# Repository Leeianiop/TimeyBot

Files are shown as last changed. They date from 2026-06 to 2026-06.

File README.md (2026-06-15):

# TimeyBot
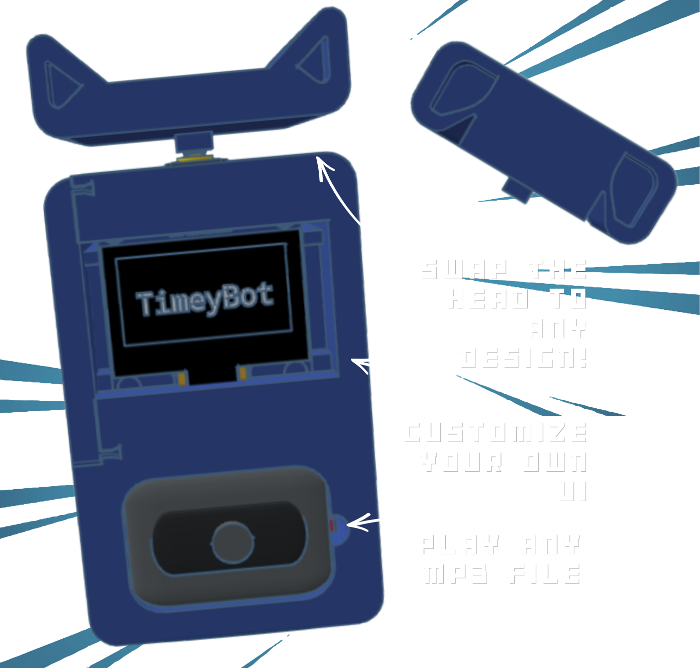
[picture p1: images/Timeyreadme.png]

## A cute Time tracker, Base functions include:
Stopwatch,
Timer,
Local Time,
Calendar reminder,
Alarm,
Music Player,
Pomodoro Tracker.
## Why Timey

It began when I was studying for exams; I always needed a study tool that was a time tracker and doubled as an audio player.  
Sure, there were phone apps to do so, but i kept finding myself scrolling whenever I go check on it.  
You could say I had been planing to make Timey for a long time  
It features all-in-one functions and can be built on to add your own Songs, Functions, Design and more.  
I made it specifically so that it doubles as a study partner, with time tracking and task reminder features and no distractions from other apps.    
## BOM

| Component | Description | Unit Price | Qty | Total |
|---|---|---|-----|---|
| ESP32 Dev Board (Micro USB) | Microcontroller | $6.03 | 1 | $6.03 |
| 128x64 1.3" OLED Display (I2C) | UI Display | $5.49 | 1 | $5.49 |
| 4Ω Speaker | Playing Music and Alarms | $3.63 | 1 | $3.63 |
| MAX98357 Amplifier | Amplify Sound | $3.27 | 1 | $3.27 |
| Jumper Wires (Female-Female) | Connect the Circuit | $1.48 | 1 | $1.48 |
| USB to Wires Cable | Power the Circuit | $1.75 | 1 | $1.75 |
| Push Button | Control the UI | $0.66 | 1 | $0.66 |
| Screw (10 pcs) | Locking in the PCB and components | $1.20 | 1 | $1.20 |
| Pin Header Female | Solder into PCB | $0.50 | 1 | $0.50 |
| DS3231 RTC module | Track local time offline | $2.21 | 1 | $2.21 |
| Pin Header Male (1x40) |Connecting components with PCB | $0.12 | 1 | $0.12 |
| 0805 SMD Ceramic Capacitor | Prevent brownout/ ESP crashes | $1.22 | 1 | $1.22 |
| Terminal Block 2p | To connect USB cable to esp | $0.12 | 1 | $0.12 |
| Hex Nut (M3) | To lock in button PCB and slider | $0.12 | 1 | $0.32 |

### Optional Storage Upgrade (For MP3 files)

| Component | Description | Price |
|---|---|---|
| Micro SD Card | Store MP3 Files | $1.13 |
| Micro SD Card Reader | Connect to ESP32 | $0.50 |

### Estimated Total Cost

**$29.33 USD**   

STL files include: (TimeyBotMainCase), (TimeyBotSlider), (TimeyBotBackplate), (Extensions file>> (TimeyBot_eDog), (TimeyBot_eCat) )  
PCB files include: (TimeyBotPCB), (TimeyBotSCH)   
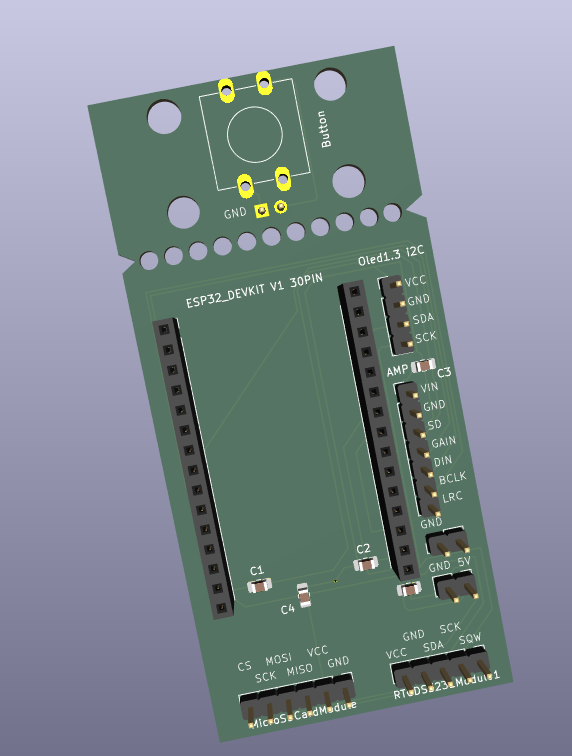
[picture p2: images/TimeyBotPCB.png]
TimeyBot
  
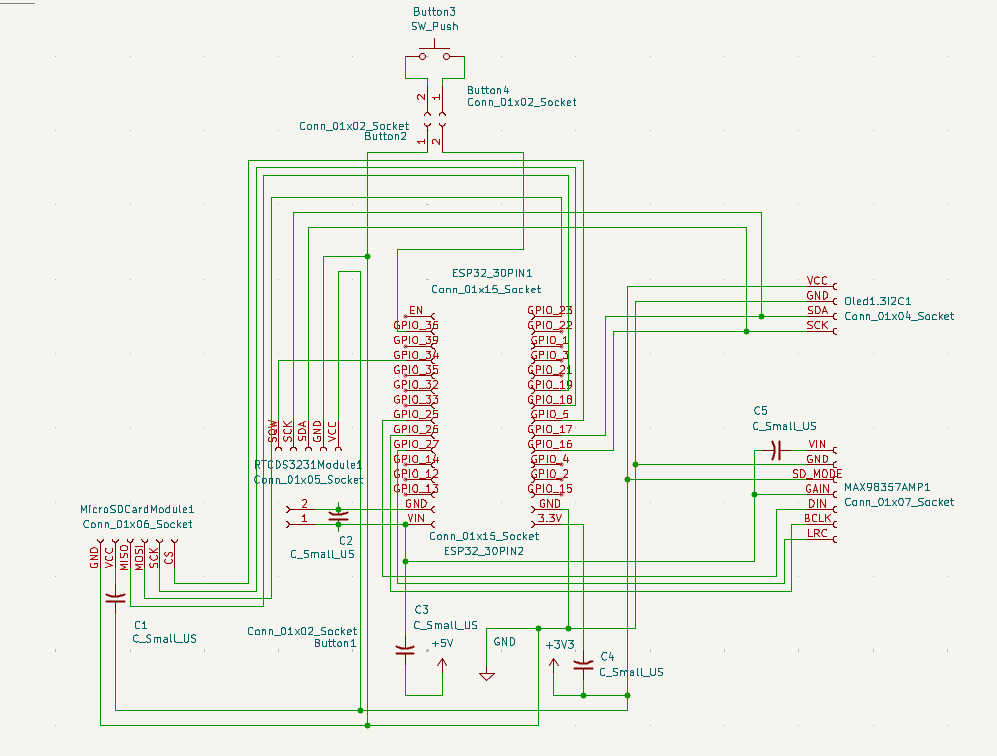
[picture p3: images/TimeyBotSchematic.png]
TimeyBot
  

## How to Use?
The starting page will be the Local Time Mode. Click the button on top (HEAD) to scroll down the menu and select different modes:
- Music Player Mode - Listening  
- Time Track Mode - Timer, Stopwatch, Alarm, Calendar Reminder  
- Study Mode - Pomodoro & Music  
## Setting up
1. Print the STL files.  
2. Upload the IDE code into the ESP32, remember to install ESP Boards and Adafruit Libraries. 
3. Wire the components into the case as shown in the Wiring Diagram or Get the PCB board and connect according so.
4. PCB goes and RTC and SD and AMP go behind where they are labeled in the STL file :)  
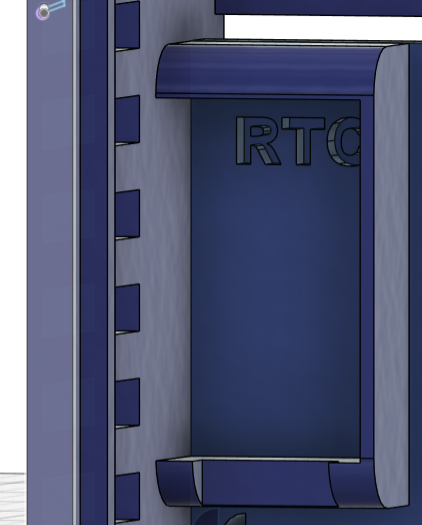
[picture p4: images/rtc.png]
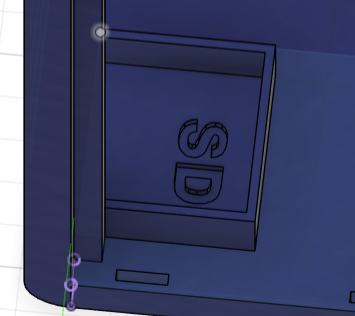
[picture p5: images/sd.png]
  
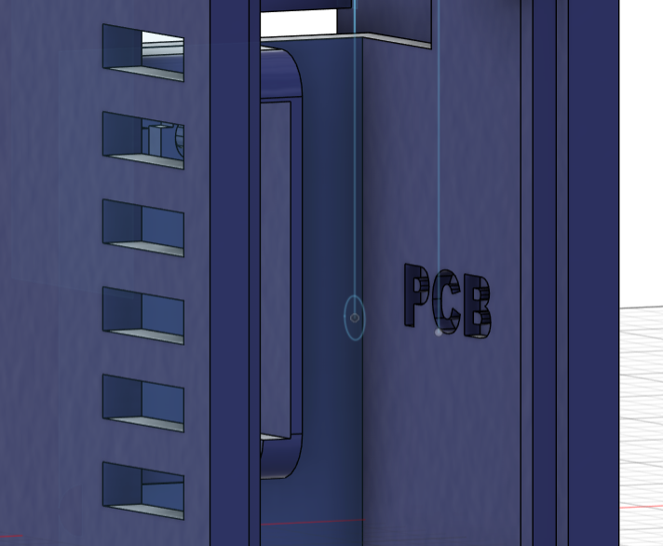
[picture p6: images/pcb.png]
   
Hope you like Mr Timey ;) 35 hours logged on this project (as of now)

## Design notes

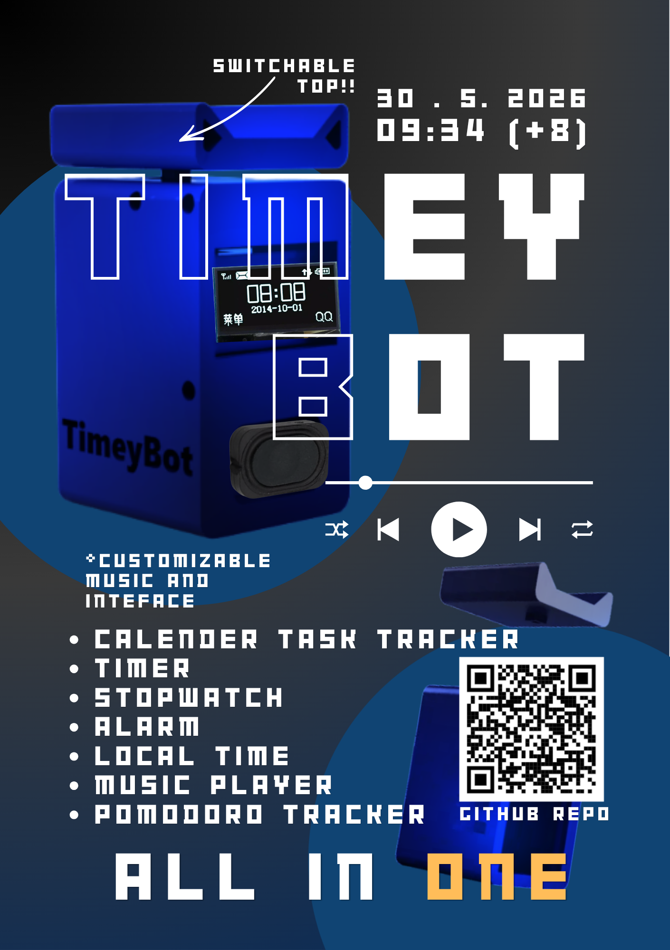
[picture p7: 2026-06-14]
images/TimeyBotZine.png

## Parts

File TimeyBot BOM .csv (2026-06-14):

Components | Description | Link | Unit Price ($) | Quantity | Total ($)
ESP32 Dev Board (microusb) | Microcontroller | https://www.lazada.com.my//products/i4353659237-s24471519541.html?urlFlag=true | $6.03 | 1 | $6.03
128x64 1.3inch Oled display (I2C) | UI display | https://www.lazada.com.my//products/i4565300946-s25774984786.html?urlFlag=true | $5.49 | 1 | $5.49
4 ohm speaker | Playing Music and Alarms | https://www.lazada.com.my//products/i4151232045-s23547423704.html?urlFlag=true | $3.63 | 1 | $3.63
MAX98357 amp | Amplify sound | https://www.lazada.com.my//products/i4826031585-s27348421411.html?urlFlag=true | $3.27 | 1 | $3.27
Jumper wires (female to female) | Connect the circuit | https://www.lazada.com.my//products/i3898574832-s22557322350.html?urlFlag=true | $1.48 | 1 | $1.48
USB to wire cable | Wire to power the circuit | https://www.lazada.com.my//products/i4633393867-s26061046516.html?urlFlag=true | $1.75 | 1 | $1.75
Push Button | Control the UI | https://www.lazada.com.my//products/i4842604827-s27498071360.html?urlFlag=true | $0.66 | 1 | $0.66
Screw (10 pcs) | Locking in the PCB and components | https://www.lazada.com.my//products/i4663837363-s26181719273.html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 | $1.20 | 1 | $1.20
Pin Header Female (1x40) | Connecting ESP with PCB | https://www.lazada.com.my//products/i4663837363-s26181719273.html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 | $0.20 | 1 | $0.20
DS3231 RTC module | Track local time offline | https://www.lazada.com.my//products/i131084606-s146041975.html?urlFlag=true&tradePath=%2CcartPriceDrop%2Ccart | $2.21 | 1 | $2.21
Pin Header Male (1x40) | Connecting components with PCB | https://www.lazada.com.my//products/i421963311-s614288662.html?urlFlag=true | $0.12 | 1 | $0.12
0805 SMD Ceramic Capacitor | Prevent brownout/ ESP crashes | https://shopee.com.my/product/265108724/42621557099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 | $1.22 | 1 | $1.22
Terminal Block 2p | To connect USB cable to esp | https://www.lazada.com.my//products/i4060872536-s22979351303.html?urlFlag=true | $0.12 | 1 | $0.12
Hex Nut (M3) | To lock in button PCB and slider | https://www.lazada.com.my//products/i2448181222-s10645857289.html?urlFlag=true | $0.32 | 1 | $0.32
Optional (Larger songs storage)
Micro SD card | Store MP3 files | https://www.lazada.com.my//products/i3905404564-s22583718858.html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 | $0.50 | 1 | $0.50
Micro SD card reader | Connect to ESP32 | https://www.lazada.com.my//products/i14860303701-s127831463438.html?urlFlag=true | $1.13 | 1 | $1.13
 |  |  |  | TOTAL: | $29.33

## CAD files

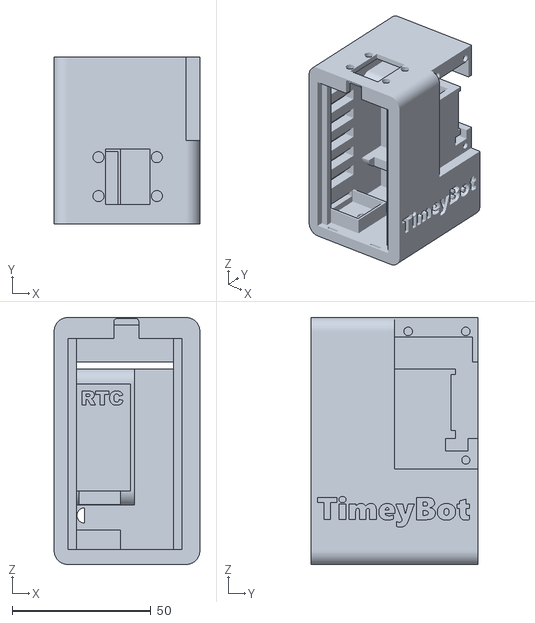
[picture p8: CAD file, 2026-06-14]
CAD/STL/TimeyBotMainCase.stl
52.5 x 60.0 x 88.9

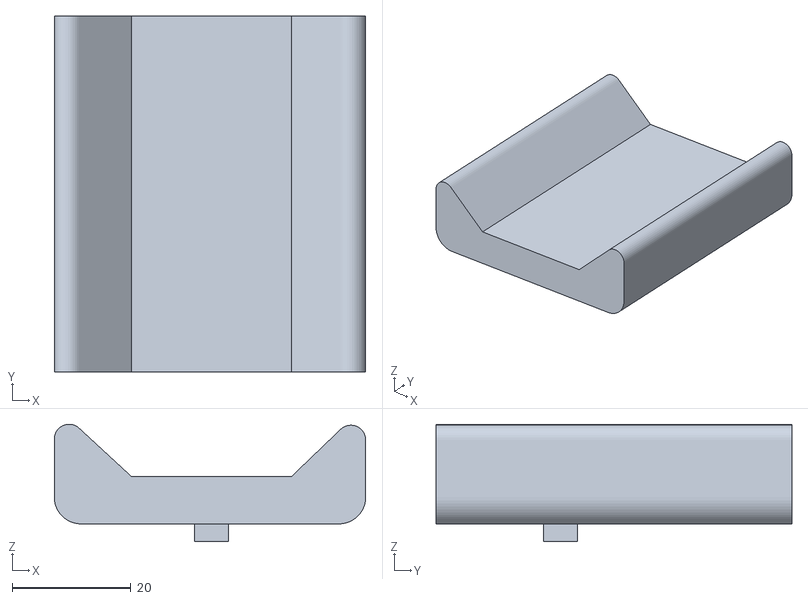
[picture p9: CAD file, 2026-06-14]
CAD/STL/Extentions/TimeyBot_eCat.stl
52.5 x 60.0 x 19.8

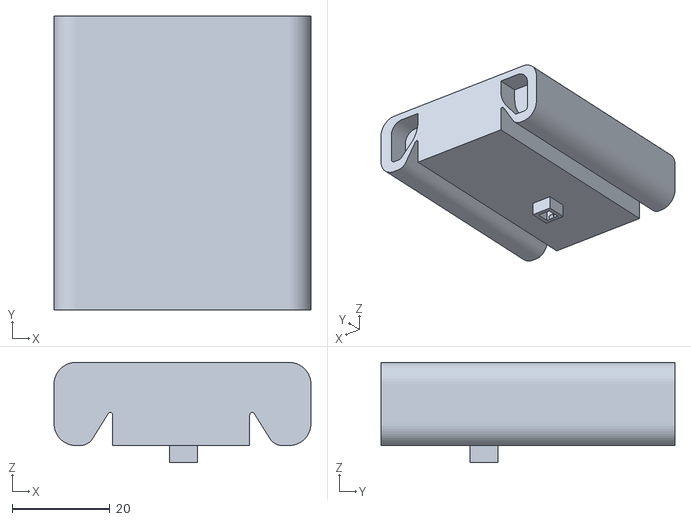
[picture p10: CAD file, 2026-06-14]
CAD/STL/Extentions/TimeyBot_eDog.stl
52.5 x 60.0 x 20.5

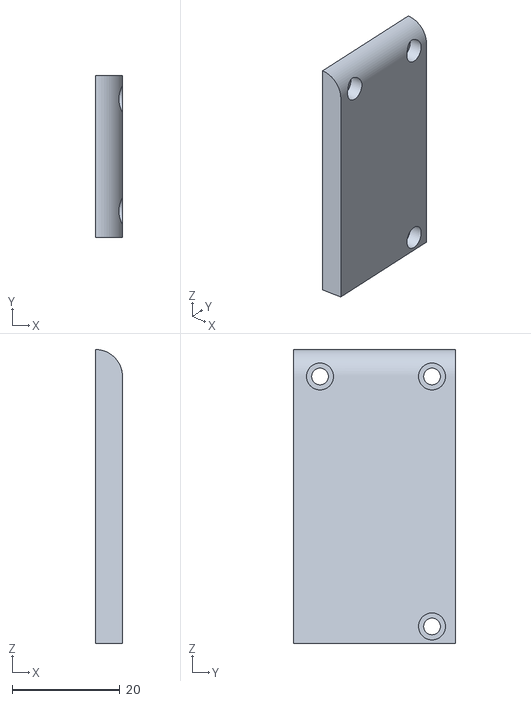
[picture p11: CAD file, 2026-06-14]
CAD/STL/TimeyBotSlider.stl
5.00 x 30.0 x 54.5

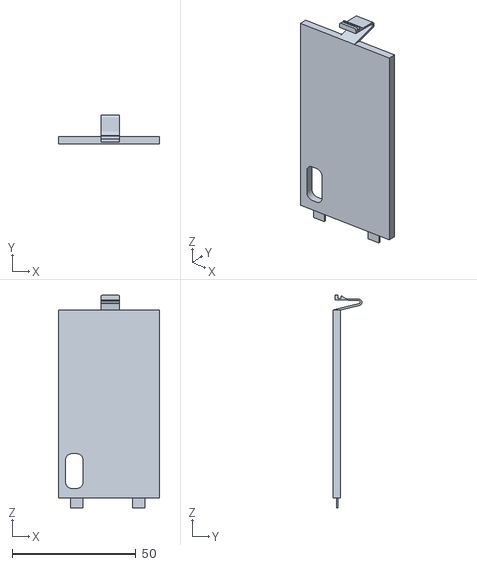
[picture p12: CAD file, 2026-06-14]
CAD/STL/TimeyBotBackplate.stl
40.8 x 11.7 x 85.9

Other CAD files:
CAD/F3D/Extentions/TimeyBot.eCat.f3d
CAD/F3D/Extentions/TimeyBot_eDog.f3d
CAD/F3D/TimeyBotBackplate.f3d
CAD/F3D/TimeyBotMainCase.f3d
CAD/F3D/TimeyBotSlider.f3d

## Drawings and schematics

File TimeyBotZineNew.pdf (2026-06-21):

# T i m e y

# T i m e y

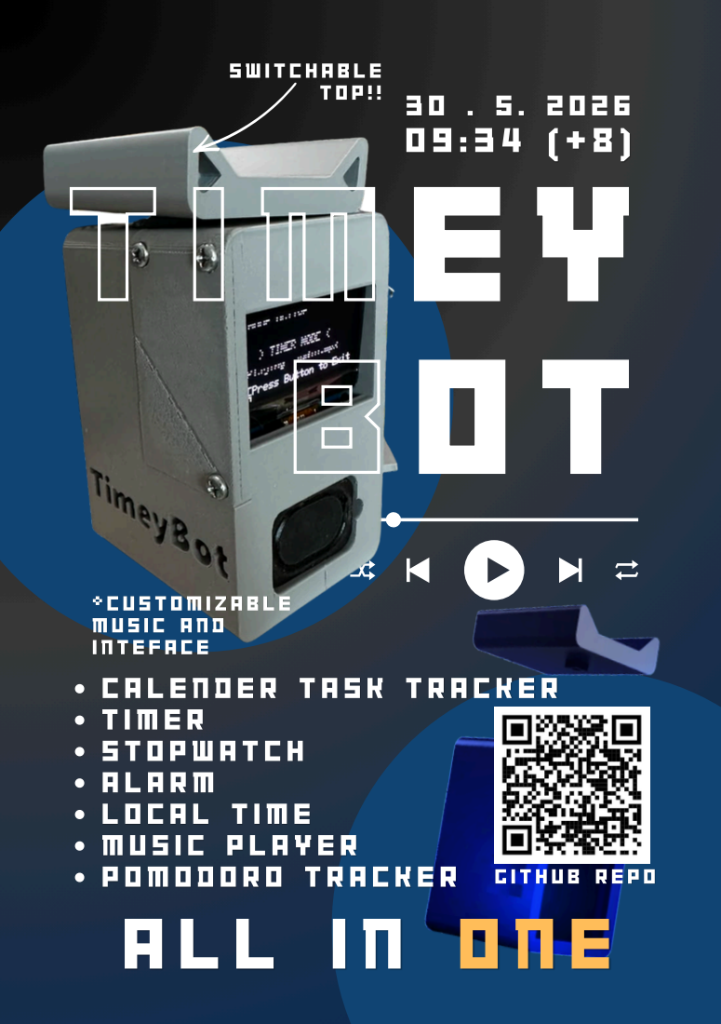
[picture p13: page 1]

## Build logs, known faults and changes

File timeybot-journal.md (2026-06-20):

# TimeyBot — Journal Export

- Exported at: 2026-06-20T15:19:27Z
- Project ID: 3963
- Entries: 25

## Entry 1
- ID: 9626
- Author: leeianiop
- Created At: 2026-05-27T10:57:30Z

### Content

TimeyBot casing done, those moments where i pause is when i'm getting the real measurements IRL haha.
I had a oled display and a speaker ready to build in.
Now that i'm thinking about it i should probably add some buttons too.
Anyways i'm using a esp32s node mcu as the microcontroller.
For the casing i added slot in features so i can reuse the components
Screenshot 2026-05-27 185709.png

### Recording Links

- https://lookout.hackclub.com/api/media/aca936d9-4302-4b63-9ccd-78aa38902488/video.mp4
- https://lookout.hackclub.com/api/media/b4b0e7d0-71a9-43bd-9ff9-4062f8d3f2a6/video.mp4
- https://lookout.hackclub.com/api/media/941186ab-774c-48eb-93c7-11b908e6de81/video.mp4

## Entry 2
- ID: 9785
- Author: leeianiop
- Created At: 2026-05-28T01:13:31Z

### Content

Made the back case pullable out with a mechanism i found from my aircon remote haha.
I also added a hole for a button at the top. 
Screenshot 2026-05-28 091316.png

### Recording Links

- https://lookout.hackclub.com/api/media/1df0b7c0-1a78-4813-b53f-61819b8887a2/video.mp4

## Entry 3
- ID: 9795
- Author: leeianiop
- Created At: 2026-05-28T02:27:48Z

### Content

Troubleshooting with printer settings and support however cannot seem to connect to the bambulab printer
Screenshot 2026-05-28 102736.png

### Recording Links

- https://lookout.hackclub.com/api/media/a85a095e-26fb-4f63-81f8-66f27bd3c90f/video.mp4
- https://lookout.hackclub.com/api/media/1affa838-77b3-40f8-9c1d-164167250a16/video.mp4
- https://lookout.hackclub.com/api/media/6a5180d8-5217-4733-aecd-22dafd21f26a/video.mp4

## Entry 4
- ID: 9825
- Author: leeianiop
- Created At: 2026-05-28T03:46:10Z

### Content

more troubleshooting with the bambu studio. tested different supports and infills along with slicing and printing the model
Screenshot 2026-05-28 114503.png

### Recording Links

- https://lookout.hackclub.com/api/media/5c71a48b-4f21-463b-a1da-840a61b8d239/video.mp4
- https://lookout.hackclub.com/api/media/1c1d758c-5e23-4d0c-b9d4-b4ee772af2d7/video.mp4

## Entry 5
- ID: 9842
- Author: leeianiop
- Created At: 2026-05-28T05:46:45Z

### Content

Finally got it printing. Managed to connect to the public printer. Had to adjust the nozzle head print size to 0.4mm, which was the error I was struggling with.
Screenshot 2026-05-28 134628.png

### Recording Links

- https://lookout.hackclub.com/api/media/663155b8-820d-4612-9923-2deb1a33bc95/video.mp4

## Entry 6
- ID: 9951
- Author: leeianiop
- Created At: 2026-05-28T17:19:43Z

### Content

Made some cute head designs to put on the button, it will look like you are petting the timer when you are using the UI. Had some concerns about the stability of it though, will need to ptrint and test one of the caps in the future
Screenshot 2026-05-29 004737.png

### Recording Links

- https://lookout.hackclub.com/api/media/dfa268cd-a97c-4cdf-9e24-2dcb3797ff1c/video.mp4
- https://lookout.hackclub.com/api/media/069e8b3b-81d4-4465-9951-9a41faa7e57b/video.mp4
- https://lookout.hackclub.com/api/media/595c66b7-45be-4036-a471-099ad555ba8f/video.mp4

## Entry 7
- ID: 10127
- Author: leeianiop
- Created At: 2026-05-29T12:36:18Z

### Content

Preparing the GitHub page of TimeyBot and started making my BOM. Had to use lazada as it has the cheapest prices in my local area and can ship quickly
Screenshot 2026-05-29 203602.png

### Recording Links

- https://lookout.hackclub.com/api/media/58fa0497-983c-4c81-a635-950b61feb98a/video.mp4

## Entry 8
- ID: 10413
- Author: leeianiop
- Created At: 2026-05-30T14:31:52Z

### Content

Started rendering designs at Fusion360 to put into My Zine and Github. Project is eensy weensy bit from submitting!
TimeyBot v256.png

### Recording Links

- https://lookout.hackclub.com/api/media/4234852c-8d47-484a-8153-8b92821760e3/video.mp4

## Entry 9
- ID: 10426
- Author: leeianiop
- Created At: 2026-05-30T15:50:46Z

### Content

Rendered some more images and started working on my zine. Thought it turned out pretty nice. Would work more on the zine if i get to build it IRL though.
Screenshot 2026-05-30 235028.png

### Recording Links

- https://lookout.hackclub.com/api/media/0a092aab-06f9-42a0-9b52-7a3acb63f3b1/video.mp4
- https://lookout.hackclub.com/api/media/e49a1ca9-9b91-457e-abcf-951449487bef/video.mp4

## Entry 10
- ID: 10658
- Author: leeianiop
- Created At: 2026-05-31T14:02:12Z

### Content

Updated the README to fit the requirements, included how to use and how to set up the bot. Also the Functionality of it too
Screenshot 2026-05-31 220148.png

### Recording Links

- https://lookout.hackclub.com/api/media/4a583a6b-3a67-41ce-bc6b-1b74bc771ffe/video.mp4

## Entry 11
- ID: 10862
- Author: leeianiop
- Created At: 2026-06-01T09:02:05Z

### Content

Realized some parts needed strong fixing. Added screw holes to the slider. Changed the back plate to a better design (which I looked at my remote for inspo :|) Made the button on top screwable too which means i'm going to make a pcb! Also added a hole in the back plate for the cable to pass through and a place to hold the sd card reader.
Screenshot 2026-06-01 165823.png
Screenshot 2026-06-01 165858.png
Screenshot 2026-06-01 165843.png
Screenshot 2026-06-01 170055.png

### Recording Links

- https://lookout.hackclub.com/api/media/66f31b4e-5d65-4539-a3e5-536cd677eb44/video.mp4

## Entry 12
- ID: 11119
- Author: leeianiop
- Created At: 2026-06-02T12:50:17Z

### Content

Added some more improvements in fusion360 ( added components, fixed spacing in the back for PCB and screws etc)
Screenshot 2026-06-02 205004.png

### Recording Links

- https://lookout.hackclub.com/api/media/eaad9281-3e57-4cba-927e-977e82870d98/video.mp4

## Entry 13
- ID: 11394
- Author: leeianiop
- Created At: 2026-06-03T15:56:59Z

### Content

Not much of a code guy, just touched on Arduino code few weeks ago, this was so much PAIN.  I typed the base code for first functions and messed up some of the indentations. Lets see if i can finish this in a week AT LEAST.
Screenshot 2026-06-03 235647.png

### Recording Links

- https://lookout.hackclub.com/api/media/b4ea31a1-70b8-4024-958e-bc2022d59612/video.mp4
- https://lookout.hackclub.com/api/media/4d4cc00d-22d9-4270-8269-72749c7ad194/video.mp4
- https://lookout.hackclub.com/api/media/deecaf63-86ad-40e9-962d-6f7d2487d171/video.mp4

## Entry 14
- ID: 12761
- Author: leeianiop
- Created At: 2026-06-09T14:05:11Z

### Content

Finally started working on the PCB, i'm thinking of having 2 separate pieces. All components connect to pcb to link the gnd and power input, also rtc module and oled share the same i2c bus connection
Screenshot 2026-06-09 214531.png

### Recording Links

- https://lookout.hackclub.com/api/media/33836b4c-7d7f-40ad-9e0a-580c6e93ade7/video.mp4
- https://lookout.hackclub.com/api/media/ca30adea-8576-4a6e-8326-14cfa5c02f43/video.mp4
- https://lookout.hackclub.com/api/media/eb6b7f75-2b40-4dc2-bb2c-49a14868603e/video.mp4
- https://lookout.hackclub.com/api/media/78d7e940-a44e-48e8-a492-8e8bf6607fb3/video.mp4
- https://lookout.hackclub.com/api/media/73bc249c-82d6-4d26-90f1-290dd2503605/video.mp4
- https://lookout.hackclub.com/api/media/7655375c-11f6-41e5-b040-906e9dcfa117/video.mp4

## Entry 15
- ID: 13015
- Author: leeianiop
- Created At: 2026-06-10T14:37:16Z

### Content

Screenshot 2026-06-10 222900.png
Made the PCB and 3d model,  all components will be connected with jumper wires, except for the RTC module.

### Recording Links

- https://lookout.hackclub.com/api/media/8cdbccbf-77c3-4fcf-851f-fd816c45c0c8/video.mp4

## Entry 16
- ID: 13207
- Author: leeianiop
- Created At: 2026-06-11T11:05:52Z

### Content

Made a new pcb because the first one didn't fit, and added the button pin header, gonna add mounting holes next
Screenshot 2026-06-11 190542.png

### Recording Links

- https://lookout.hackclub.com/api/media/2806812f-cc04-4156-ae7f-921718eb8e70/video.mp4

## Entry 17
- ID: 13222
- Author: leeianiop
- Created At: 2026-06-11T13:07:20Z

### Content

Made screws/ mounting holes for the button PCB. was crashing out because the lines kept changing nets. (speaking of nets the world cup is about to start (random))
Screenshot 2026-06-11 210324.png

### Recording Links

- https://lookout.hackclub.com/api/media/cf07cd95-1e78-4824-a3a8-8bfcd8826d7b/video.mp4

## Entry 18
- ID: 13661
- Author: leeianiop
- Created At: 2026-06-13T06:54:33Z

### Content

I made some firmware. Tested to use which pins and library, and learned some oled programming basics. 
Screenshot 2026-06-13 145417.png

### Recording Links

- https://lookout.hackclub.com/api/media/7df9c961-e835-4e45-be9e-13f5cd94508c/video.mp4

## Entry 19
- ID: 13671
- Author: leeianiop
- Created At: 2026-06-13T07:43:16Z

### Content

Made some fusion progress, added an RTC housing cage, and also added text at the back for other users to know which parts go where.
Screenshot 2026-06-13 154304.png

### Recording Links

- https://lookout.hackclub.com/api/media/2905d5b5-91f6-45b1-8517-32c81bcb9b92/video.mp4

## Entry 20
- ID: 13760
- Author: leeianiop
- Created At: 2026-06-13T16:36:39Z

### Content

Made the PCB into one peice and made the top breakable for the button PCB. Also had to swtich the esp to the left side to prevent sizing problems with the RTC module. Rendered some CAD images and edited the zine and BOM as well.
Screenshot 2026-06-14 003629.png

### Recording Links

- https://lookout.hackclub.com/api/media/f2edabfc-0006-4ef3-a692-de537cd8164d/video.mp4

## Entry 21
- ID: 13923
- Author: leeianiop
- Created At: 2026-06-14T09:12:56Z

### Content

Screenshot 2026-06-14 171052.png
Measured the back compartments in fsion and realized there was no space, had to remake the PCB (3RD TIME!!) at least i have the final PCB now and everything fits

### Recording Links

- https://lookout.hackclub.com/api/media/93eea880-acfb-4b24-9d4c-3b102e27579c/video.mp4

## Entry 22
- ID: 13949
- Author: leeianiop
- Created At: 2026-06-14T11:04:03Z

### Content

I did some fusion exporting to bambu lab and updated the github with new PCB and CAD models along with the new zine 
Screenshot 2026-06-14 180019.png

### Recording Links

- https://lookout.hackclub.com/api/media/3b24968e-e1ac-4d63-a888-68967dfeedab/video.mp4

## Entry 23
- ID: 14205
- Author: leeianiop
- Created At: 2026-06-15T09:29:41Z

### Content

Average firmware crash out. I tried the full code, my oled doesn't even light up. I tried a test code and it crashed. The thrid time it uploaded but my oled still malfunctioning. Will check on the hardware problem, maybe its a cable issue
Screenshot 2026-06-15 172807.png

### Recording Links

- https://lookout.hackclub.com/api/media/4f8b9889-aa07-45fa-8969-e430c02bb2f0/video.mp4

## Entry 24
- ID: 14241
- Author: leeianiop
- Created At: 2026-06-15T13:28:00Z

### Content

My programming cable is likely the issue, the UI keeps resetting, i will have to trust my code untill i get a better one :(
Screenshot 2026-06-15 212705.png

### Recording Links

- https://lookout.hackclub.com/api/media/bb54c09f-d2da-4d2e-b311-0708fed76065/video.mp4

## Entry 25
- ID: 14250
- Author: leeianiop
- Created At: 2026-06-15T14:27:12Z

### Content

I did some final checking on the repo, added teh gerber fies, and ino files and some images in the readme as well
Screenshot 2026-06-15 222653.png

### Recording Links

- https://lookout.hackclub.com/api/media/cbd69450-d8c1-4c18-bc44-79310bb84149/video.mp4

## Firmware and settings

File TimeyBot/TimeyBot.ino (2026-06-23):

#define AUDIO_NO_WEB    
#define AUDIO_NO_WAV    
#define AUDIO_NO_FLAC
#define AUDIO_NO_AAC
#define AUDIO_NO_M4A

#include <Wire.h>
#include <SPI.h>
#include <Adafruit_GFX.h>
#include <Adafruit_SSD1306.h>
#include "Audio.h" 
#include "LittleFS.h"

// ---------------- OLED SPI Pins ----------------
#define SCREEN_WIDTH 128
#define SCREEN_HEIGHT 64
#define OLED_MOSI 23
#define OLED_CLK  18
#define OLED_DC   16
#define OLED_CS   5
#define OLED_RESET 17

Adafruit_SSD1306 display(SCREEN_WIDTH, SCREEN_HEIGHT, &SPI, OLED_DC, OLED_RESET, OLED_CS);

// ---------------- Audio & Button Pins ----------------
#define BUTTON_PIN 4
#define I2S_BCLK   26
#define I2S_LRC    25
#define I2S_DOUT   27

Audio audio;

// ---------------- UI States ----------------
enum UIState {
  STATE_SET_HOURS,      
  STATE_SET_MINUTES,    
  STATE_CONFIRM_SETUP,  
  STATE_CLOCK,
  STATE_MENU,
  STATE_TIMER,          // Fully coded
  STATE_ALARM_HOURS,    // Fully coded dynamic settings
  STATE_ALARM_MINUTES,  
  STATE_ALARM_ACTIVE,   
  STATE_STOPWATCH,      // Fully coded
  STATE_SOUND_PLAY
};

UIState currentState = STATE_SET_HOURS; 
int menuSelection = 0; 
int scrollOffset = 0; 
const int MENU_ITEMS_COUNT = 5;
const char* menuItems[] = {
  "Timer Mode", 
  "Alarm Set", 
  "Stopwatch", 
  "Songs (Earrings)", 
  "< Back to Clock"
};

int confirmSelection = 0; 

// ---------------- Button Timing Variables ----------------
unsigned long lastButtonPressTime = 0;
bool singleClickPending = false;
unsigned long doubleClickGap = 250; 

// ---------------- Clock Variables ----------------
unsigned long lastClockUpdate = 0;
int hours = 0;
int minutes = 0;
int seconds = 0; 

// ---------------- Mode Functional Variables ----------------
// Timer variables
int timerTargetMinutes = 1; 
unsigned long timerStartTime = 0;
unsigned long timerDurationMs = 0;
bool timerRunning = false;

// Alarm variables
int alarmHours = 0;
int alarmMinutes = 0;
bool alarmEnabled = false;
bool alarmRinging = false;

// Stopwatch variables
unsigned long stopwatchElapsedMs = 0;
unsigned long stopwatchLastPausedMs = 0;
unsigned long stopwatchStartTime = 0;
bool stopwatchRunning = false;

void setup() {
  pinMode(BUTTON_PIN, INPUT_PULLUP);
  Serial.begin(115200);

  if (!display.begin(SSD1306_SWITCHCAPVCC)) {
    Serial.println("OLED allocation failed");
    while (1);
  }

  display.clearDisplay();
  display.setTextColor(SSD1306_WHITE);
  display.setTextWrap(false);

  if(!LittleFS.begin()){
     Serial.println("An Error has occurred while mounting LittleFS");
  }

  audio.setPinout(I2S_BCLK, I2S_LRC, I2S_DOUT);
  audio.setVolume(12); 
}

void loop() {
  audio.loop();

  // --- Dynamic Double Click Adjustment ---
  if (currentState == STATE_SET_HOURS || currentState == STATE_SET_MINUTES || currentState == STATE_ALARM_HOURS || currentState == STATE_ALARM_MINUTES) {
    doubleClickGap = 180; 
  } else {
    doubleClickGap = 350; 
  }

  // --- Button Input Logic ---
  static bool lastButtonState = HIGH;
  bool currentButtonState = digitalRead(BUTTON_PIN);
  bool actionScroll = false;
  bool actionEnter = false;

  if (lastButtonState == HIGH && currentButtonState == LOW) {
    unsigned long clickTime = millis();
    if (clickTime - lastButtonPressTime < doubleClickGap) {
      actionEnter = true;          
      singleClickPending = false;  
    } else {
      singleClickPending = true;   
    }
    lastButtonPressTime = clickTime;
    delay(60); 
  }
  lastButtonState = currentButtonState;

  if (singleClickPending && (millis() - lastButtonPressTime > doubleClickGap)) {
    actionScroll = true;
    singleClickPending = false;
  }

  // --- Background Clock Tracker ---
  if (currentState != STATE_SET_HOURS && currentState != STATE_SET_MINUTES && currentState != STATE_CONFIRM_SETUP) {
    if (millis() - lastClockUpdate >= 1000) {
      lastClockUpdate = millis();
      seconds++;
      if (seconds >= 60) {
        seconds = 0;
        minutes++;
        if (minutes >= 60) {
          minutes = 0;
          hours++;
          if (hours >= 24) hours = 0;
        }
      }
      
      // Check active alarm match once per minute change
      if (alarmEnabled && seconds == 0 && hours == alarmHours && minutes == alarmMinutes) {
        alarmRinging = true;
        currentState = STATE_SOUND_PLAY;
        audio.connecttoFS(LittleFS, "/Earrings.mp3");
      }
    }
  }

  // --- UI Logic State Machine ---
  switch (currentState) {
    case STATE_SET_HOURS:
      if (actionScroll) { hours++; if (hours >= 24) hours = 0; }
      if (actionEnter) { currentState = STATE_SET_MINUTES; delay(150); }
      break;

    case STATE_SET_MINUTES:
      if (actionScroll) { minutes++; if (minutes >= 60) minutes = 0; }
      if (actionEnter) { currentState = STATE_CONFIRM_SETUP; confirmSelection = 0; delay(150); }
      break;

    case STATE_CONFIRM_SETUP:
      if (actionScroll) confirmSelection = (confirmSelection == 0) ? 1 : 0;
      if (actionEnter) {
        if (confirmSelection == 0) { lastClockUpdate = millis(); seconds = 0; currentState = STATE_CLOCK; }
        else { currentState = STATE_SET_HOURS; }
        delay(150);
      }
      break;

    case STATE_CLOCK:
      if (actionScroll || actionEnter) { currentState = STATE_MENU; menuSelection = 0; scrollOffset = 0; }
      break;

    case STATE_MENU:
      if (actionScroll) {
        menuSelection++;
        if (menuSelection >= MENU_ITEMS_COUNT) { menuSelection = 0; scrollOffset = 0; }
        if (menuSelection - scrollOffset >= 2) scrollOffset++;
      }
      if (actionEnter) {
        if (menuSelection == 0)      { currentState = STATE_TIMER; timerRunning = false; }
        else if (menuSelection == 1) { currentState = STATE_ALARM_HOURS; alarmHours = 0; }
        else if (menuSelection == 2) { currentState = STATE_STOPWATCH; }
        else if (menuSelection == 3) {
          currentState = STATE_SOUND_PLAY;
          alarmRinging = false;
          audio.connecttoFS(LittleFS, "/Earrings.mp3");
        } 
        else if (menuSelection == 4) currentState = STATE_CLOCK;
        delay(150);
      }
      break;

    case STATE_TIMER:
      if (!timerRunning) {
        if (actionScroll) { timerTargetMinutes++; if (timerTargetMinutes > 60) timerTargetMinutes = 1; }
        if (actionEnter) { timerRunning = true; timerStartTime = millis(); timerDurationMs = (unsigned long)timerTargetMinutes * 60000; }
      } else {
        if (actionEnter) { timerRunning = false; } // Interrupted/Cancel
        if (millis() - timerStartTime >= timerDurationMs) {
          timerRunning = false;
          currentState = STATE_SOUND_PLAY;
          audio.connecttoFS(LittleFS, "/Earrings.mp3");
        }
      }
      if (actionScroll && timerRunning) { currentState = STATE_MENU; timerRunning = false; } // Exit if scrolled while running
      break;

    case STATE_ALARM_HOURS:
      if (actionScroll) { alarmHours++; if (alarmHours >= 24) alarmHours = 0; }
      if (actionEnter) { currentState = STATE_ALARM_MINUTES; alarmMinutes = 0; delay(150); }
      break;

    case STATE_ALARM_MINUTES:
      if (actionScroll) { alarmMinutes++; if (alarmMinutes >= 60) alarmMinutes = 0; }
      if (actionEnter) { alarmEnabled = true; currentState = STATE_ALARM_ACTIVE; delay(150); }
      break;

    case STATE_ALARM_ACTIVE:
      if (actionScroll) { alarmEnabled = false; currentState = STATE_MENU; } // Disable alarm
      if (actionEnter) { currentState = STATE_MENU; } // Keep active, exit menu view
      break;

    case STATE_STOPWATCH:
      if (actionScroll) { // Pause / Unpause toggle
        if (!stopwatchRunning) {
          stopwatchRunning = true;
          stopwatchStartTime = millis() - stopwatchElapsedMs;
        } else {
          stopwatchRunning = false;
          stopwatchElapsedMs = millis() - stopwatchStartTime;
        }
      }
      if (actionEnter) { // Reset or Back control
        if (stopwatchElapsedMs == 0 && !stopwatchRunning) {
          currentState = STATE_MENU;
        } else {
          stopwatchRunning = false;
          stopwatchElapsedMs = 0;
        }
      }
      break;

    case STATE_SOUND_PLAY:
      if (actionEnter || actionScroll) { 
        audio.stopSong(); 
        currentState = alarmRinging ? STATE_ALARM_ACTIVE : STATE_MENU;
        alarmRinging = false;
      }
      break;
  }

  // --- Render to Display ---
  display.clearDisplay();
  display.setTextColor(SSD1306_WHITE); 

  if (currentState == STATE_SET_HOURS) {
    display.setTextSize(1); display.setCursor(16, 6); display.print("SETUP: SET HOUR");
    display.setTextSize(4); display.setCursor(40, 20);
    if(hours < 10) display.print("0"); display.print(hours);
    display.setTextSize(1); display.setCursor(6, 54); display.print("Clk: +1 | Dbl: Next");

  } else if (currentState == STATE_SET_MINUTES) {
    display.setTextSize(1); display.setCursor(10, 6); display.print("SETUP: SET MINUTE");
    display.setTextSize(4); display.setCursor(40, 20);
    if(minutes < 10) display.print("0"); display.print(minutes);
    display.setTextSize(1); display.setCursor(6, 54); display.print("Clk: +1 | Dbl: Verify");

  } else if (currentState == STATE_CONFIRM_SETUP) {
    display.setTextSize(1); display.setCursor(14, 4); display.print("2FA TIME VERIFY");
    display.setCursor(12, 16); display.print("Time: ");
    if(hours < 10) display.print("0"); display.print(hours); display.print(":");
    if(minutes < 10) display.print("0"); display.print(minutes);

    int yOpt1 = 34, yOpt2 = 48;
    if (confirmSelection == 0) { display.fillRect(2, yOpt1 - 2, 124, 13, SSD1306_WHITE); display.setTextColor(SSD1306_BLACK); }
    display.setCursor(6, yOpt1); display.print("> CONFIRM & START"); display.setTextColor(SSD1306_WHITE);

    if (confirmSelection == 1) { display.fillRect(2, yOpt2 - 2, 124, 13, SSD1306_WHITE); display.setTextColor(SSD1306_BLACK); }
    display.setCursor(6, yOpt2); display.print("> GO BACK & EDIT"); display.setTextColor(SSD1306_WHITE);

  } else if (currentState == STATE_CLOCK) {
    display.setTextSize(1); display.setCursor(40, 6); display.print("TimeyBot");
    display.setTextSize(4); display.setCursor(4, 22);
    if(hours < 10) display.print("0"); display.print(hours); display.print(":");
    if(minutes < 10) display.print("0"); display.print(minutes);
    display.setTextSize(1); display.setCursor(34, 54); display.print("Click=Menu");

  } else if (currentState == STATE_MENU) {
    display.setTextSize(1); display.setCursor(50, 4); display.print("MENU");
    display.drawFastHLine(0, 14, 128, SSD1306_WHITE);

    for (int i = scrollOffset; i < MENU_ITEMS_COUNT && i < scrollOffset + 2; i++) {
      int yPos = 20 + ((i - scrollOffset) * 16);
      if (i == menuSelection) { display.fillRect(0, yPos - 3, 128, 15, SSD1306_WHITE); display.setTextColor(SSD1306_BLACK); }
      else { display.setTextColor(SSD1306_WHITE); }
      display.setCursor(8, yPos); display.print(menuItems[i]);
    }
    display.setTextColor(SSD1306_WHITE);
    display.setCursor(14, 54); display.print("Clk=Down  Dbl=OK");

  } else if (currentState == STATE_TIMER) {
    display.setTextSize(1); display.setCursor(48, 4); display.print("TIMER");
    if (!timerRunning) {
      display.setCursor(20, 20); display.print("Set: "); display.print(timerTargetMinutes); display.print(" Mins");
      display.setCursor(6, 54); display.print("Clk: +1m  Dbl: Start");
    } else {
      unsigned long remainingMs = timerDurationMs - (millis() - timerStartTime);
      int remMin = remainingMs / 60000;
      int remSec = (remainingMs % 60000) / 1000;
      display.setTextSize(3); display.setCursor(24, 20);
      if (remMin < 10) display.print("0"); display.print(remMin); display.print(":");
      if (remSec < 10) display.print("0"); display.print(remSec);
      display.setTextSize(1); display.setCursor(14, 54); display.print("Dbl Click to Stop");
    }

  } else if (currentState == STATE_ALARM_HOURS || currentState == STATE_ALARM_MINUTES) {
    display.setTextSize(1); display.setCursor(32, 4); display.print("ALARM SETUP");
    display.setTextSize(3); display.setCursor(24, 20);
    if(alarmHours < 10) display.print("0"); display.print(alarmHours); display.print(":");
    if(alarmMinutes < 10) display.print("0"); display.print(alarmMinutes);
    display.setTextSize(1); display.setCursor(4, 54);
    if (currentState == STATE_ALARM_HOURS) display.print("Clk:Hour+1 Dbl:MinSet");
    else display.print("Clk:Min+1  Dbl:Activate");

  } else if (currentState == STATE_ALARM_ACTIVE) {
    display.setTextSize(1); display.setCursor(32, 4); display.print("ALARM ACTIVE");
    display.setCursor(14, 24); display.print("Target -> ");
    if(alarmHours < 10) display.print("0"); display.print(alarmHours); display.print(":");
    if(alarmMinutes < 10) display.print("0"); display.print(alarmMinutes);
    display.setCursor(4, 54); display.print("Clk:Dismiss Dbl:Menu");

  } else if (currentState == STATE_STOPWATCH) {
    display.setTextSize(1); display.setCursor(32, 4); display.print("STOPWATCH");
    unsigned long currentElapsed = stopwatchElapsedMs;
    if (stopwatchRunning) currentElapsed = millis() - stopwatchStartTime;
    int displayMin = currentElapsed / 60000;
    int displaySec = (currentElapsed % 60000) / 1000;
    int displayMs  = (currentElapsed % 1000) / 10;
    
    display.setTextSize(2); display.setCursor(16, 22);
    if (displayMin < 10) display.print("0"); display.print(displayMin); display.print(":");
    if (displaySec < 10) display.print("0"); display.print(displaySec); display.print(".");
    if (displayMs < 10) display.print("0"); display.print(displayMs);
    
    display.setTextSize(1); display.setCursor(4, 54);
    display.print(stopwatchRunning ? "Clk:Pause | Dbl:Reset" : "Clk:Start | Dbl:Exit");

  } else if (currentState == STATE_SOUND_PLAY) {
    display.setTextSize(1); display.setCursor(22, 6);
    display.print(alarmRinging ? "!!! ALARM !!!" : "TimeyBot Music");
    display.setCursor(6, 26); display.print("Playing:");
    display.setCursor(6, 40); display.print("Earrings.mp3");
    display.setCursor(20, 54); display.print("Tap Key to Dismiss");
  }

  display.display(); 
}

void audio_info(const char *info){
    Serial.print("audio_info: ");
    Serial.println(info);
}

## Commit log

2026-06-14 Create CAD
2026-06-14 Clarify wiring instructions in README
    Updated instructions for wiring components in the setup section.
2026-06-15 Rename TimeyBot PCB.kicad_pcb to TimeyBotPCB.kicad_pcb
    [TimeyBotPCB.kicad_pcb]
2026-06-15 Rename ~TimeyBot PCB.kicad_pro.lck to ~TimeyBotPCB.kicad_pro.lck
2026-06-15 Rename TimeyBot SCH.kicad_sch to TimeyBotSCH.kicad_sch
    [TimeyBotSCH.kicad_sch]
2026-06-15 Rename TimeyBot PCB.kicad_pro to TimeyBotPCB.kicad_pro
